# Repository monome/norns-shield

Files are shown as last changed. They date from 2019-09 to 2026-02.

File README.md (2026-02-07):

# norns-shield

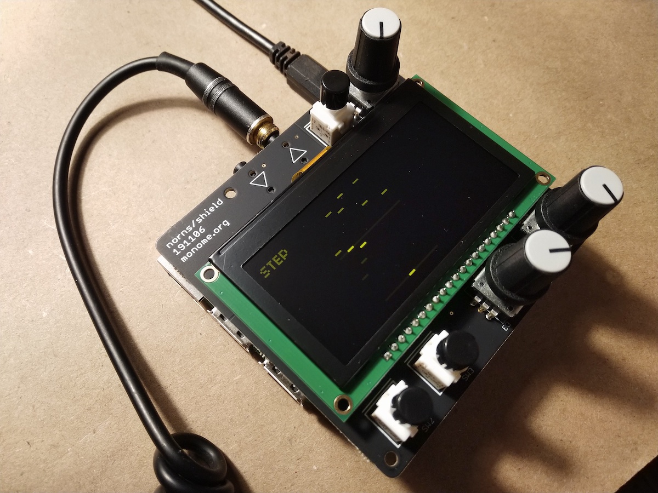
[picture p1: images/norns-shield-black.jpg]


minimal/tiny open-source/DIY shield for Raspberry Pi boards, providing hardware compatibility with the [norns](https://monome.org/docs/norns) ecosystem. designed by monome (brian crabtree, aka @tehn).

all discussion happens at [llllllll.co](https://llllllll.co/t/norns-shield-final/58810).

please be very aware that this project is no longer directly supported by [monome](https://monome.org). do not email us asking for build help or debugging. we also no longer sell boards or kits, we do not have leftovers laying around, and we do not provide repair services.

## donate

we've made these files freely available to further the exploration and design of new musical instruments. the shield relies on years of development, and we continue to maintain and evolve the platform. we hope you'll consider making a donation towards this effort.

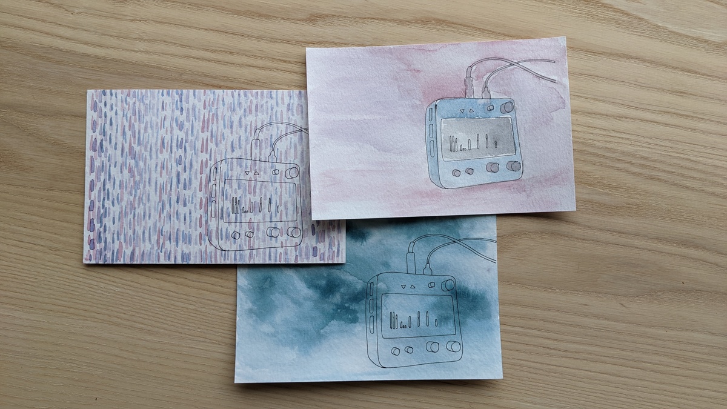
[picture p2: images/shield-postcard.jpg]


direct donations accepted via [paypal](https://paypal.me/tehn/20).

## specifications

- audio codec: CS4270 (or CS4271 on v211028)
- audio jacks: 3.5mm stereo in/out, line level
- OLED: NHD-2.7-12864WDW3
- 3x pushbuttons, 3x rotary encoders

## versions

there are three versions of the circuit:

- 191106: original version
- 210330: updated with more robust (through hole) audio jacks, better noise isolation
- 211028: different codec (due to semiconductor shortages) which requires op amps and many many more passives

we _highly_ recommend 210330 if you're building a new board, and we suggest pairing it with a pi 3B+. the Pi 4 will work with all of the above, but the wifi transciever is noisier and the physical footprint does not fit as well because the ethernet and USB ports were moved around. 

all versions are provided here as reference for repairing existing boards.

## troubleshooting

- if using a Pi 4, you may need to cover the top metal of the USB and ethernet ports on the Pi 4 with electrical tape (something nonconductive) to prevent shorting if the assembly is squeezed tight.
- most soldering problems can be solved simply by reheating solder joints. bad solders can result in various problems: screen doesn't turn on, knobs/keys don't work.
- use a good SD card, not a cheap one. if you're having trouble, try using a different card.
- be sure to use the correct power supply. the pi will not power well from a laptop and you'll get confusing errors. get a dedicated 2A USB supply, or very high output USB battery.

## notes

- the shield does not have a headphone output, but headphones work fine on the main output. the headphone gain level within the norns menu does nothing in this case.
- the battery indication will not function, as there's no battery.

## mechanicals

- 2 Female Threaded Hex Standoff Aluminum, 3/16" Hex, 5/16" Long, 2-56 Thread 91780A104
- 2 Female Threaded Hex Standoff Aluminum, 3/16" Hex, 5/8" Long, 2-56 Thread 91780A111
- 2 Female Threaded Hex Standoff Aluminum, 3/16" Hex, 3/4" Long, 2-56 Thread 91780A113
- 4 Male-Female Threaded Hex Standoff Aluminum, 3/16" Hex Size, 1/2" Long, 2-56 Thread Size 93505A213
- 4 Off-White Nylon Unthreaded Spacer 1/4" OD, 3/32" Long, for Number 6 Screw Size 94639A247
- 8 Black-Oxide 18-8 Stainless Steel Pan Head Phillips Screws 2-56 Thread, 1/4" Long 91249A050
- 2 Black-Oxide 18-8 Stainless Steel Pan Head Phillips Screws 2-56 Thread, 3/8" Long 91249A054

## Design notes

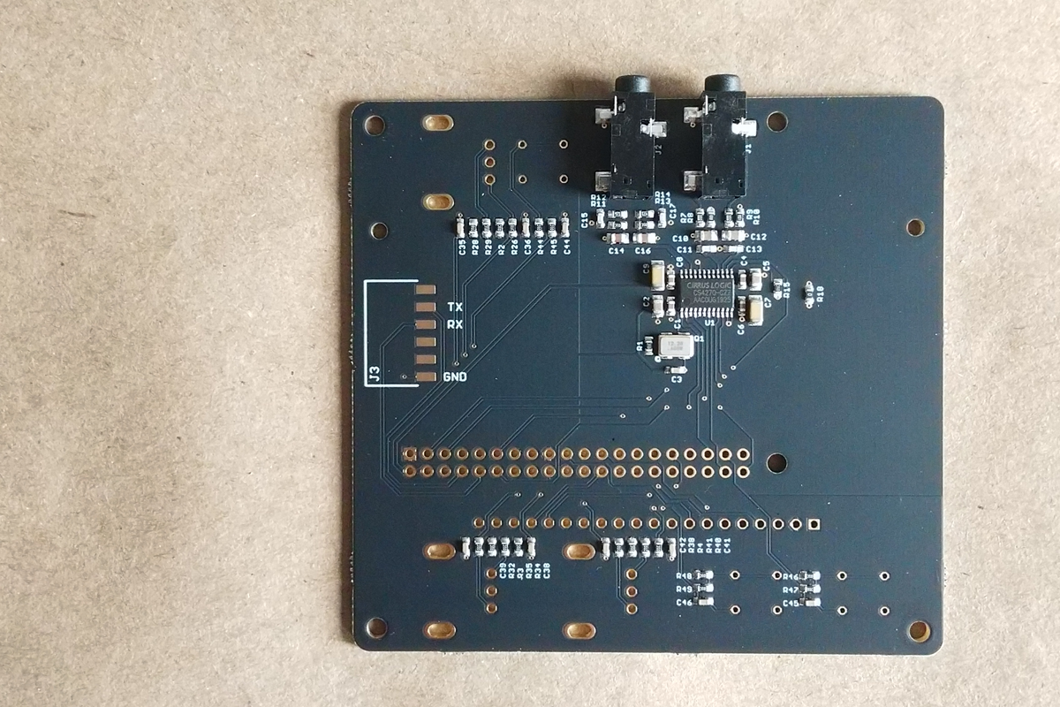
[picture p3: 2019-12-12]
images/norns-shield.png

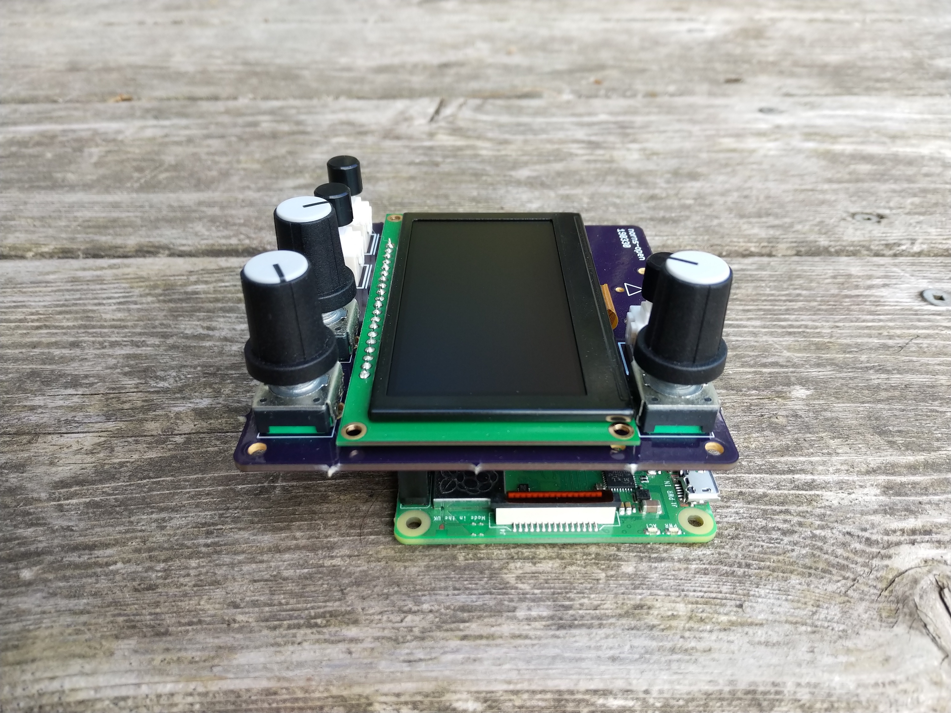
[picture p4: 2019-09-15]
images/norns-shield-side.jpg

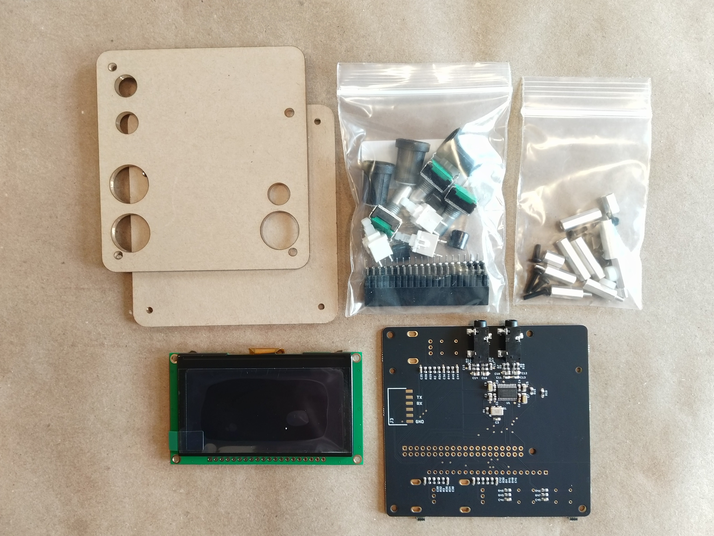
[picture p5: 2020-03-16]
images/ns-kit.jpg

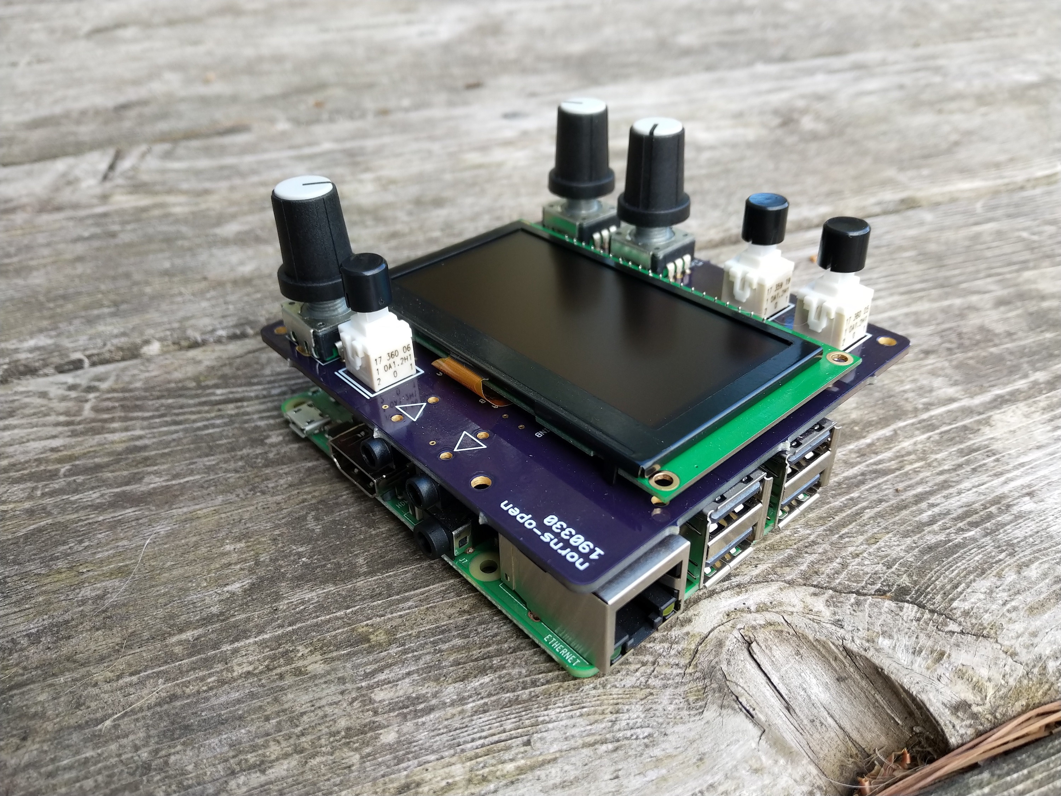
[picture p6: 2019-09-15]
images/norns-shield-angle.jpg

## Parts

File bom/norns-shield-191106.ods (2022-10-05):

Query | Qty | Manufacturer | MPN | Octopart URL | Part Description | Description | Schematic Reference
PEC11R-4015F-N0024 | 3 | Bourns | PEC11R-4015F-N0024 | https://octopart.com/pec11r-4015f-n0024-bourns-26648251 | 24 Pulse Incremental Mechanical Rotary Encoder w/ 6 mm Flat Shaft | Through Hole | ENC
1212-1105-ND | 1 | Preci-Dip | 310-87-120-41-001101 | https://octopart.com/310-87-120-41-001101-preci-dip-21424261 | Conn Socket Strip SKT 20 POS 2.54mm Solder ST Thru-Hole | OLED128X64 | U$1
PVA1 OA H1 1.2N V2 | 3 | C&K Components | PVA1OAH11.2NV2 | https://octopart.com/pva1oah11.2nv2-c%26k+components-47645791 | Switch Push Button DPST Square Button 0.1A 32VDC Momentary Contact PC Pins Thru-Hole | PVA1 | SW1, SW2, SW3
1528-1969-ND | 1 | Adafruit Industries | 1992 | https://octopart.com/1992-adafruit+industries-53880115 | GPIO Header for Raspberry Pi A+/B+ - Tall 2x20 Female Header | RASPI_BOARD_B+#_E3 | X1
1212-1149-ND | 1 | Preci-Dip | 350-80-120-00-001101 | https://octopart.com/350-80-120-00-001101-preci-dip-21642300 | Conn Unshrouded Header HDR 20 POS 2.54mm Solder ST Thru-Hole Box | for OLED
NHD-2.7-12864WDY3 | 1 | Newhaven Display | NHD-2.7-12864WDY3 | https://octopart.com/nhd-2.7-12864wdy3-newhaven+display-84706410 | OLED Displays & Accessories 2.7 in Yellow OLED 128 x 64 | OLED
311-0.0GRTR-ND | 1 | Yageo | RC0603JR-070RL | https://octopart.com/rc0603jr-070rl-yageo-1241539 | RC Series 0603 0.1 W 0 Ohm Jumper Surface Mount Thick Film Chip Resistor | 0 | R18
RC0603FR-071K5L | 2 | Yageo | RC0603FR-071K5L | https://octopart.com/rc0603fr-071k5l-yageo-55458478 | Res General Purpose Thick Film 0603 1.5K Ohm 1% 1/10W ±100ppm/°C Molded SMD Paper T/R | 1.5k | R8, R10
311-1343-2-ND | 4 | Yageo | CC0603ZRY5V9BB104 | https://octopart.com/cc0603zry5v9bb104-yageo-4507169 | Multilayer Ceramic Capacitor, 0.1 uF, 50 V, -20, +80%, Y5V, 0603 [1608 Metric] | 100n | C1, C4, C6, C8
RC0603FR-0710KL | 22 | Yageo | RC0603FR-0710KL | https://octopart.com/rc0603fr-0710kl-yageo-40025538 | Res General Purpose Thick Film 0603 10K Ohm 1% 1/10W ±100ppm/°C Molded SMD Paper T/R | 10k | R1, R2, R3, R4, R11, R13, R15, R26, R28, R29, R32, R34, R35, R38, R40, R41, R44, R45, R46, R47, R48, R49
CC0603KRX7R9BB103 | 10 | Yageo | CC0603KRX7R9BB103 | https://octopart.com/cc0603krx7r9bb103-yageo-192938 | Multilayer Ceramic Capacitor, 0.01 uF, 50 V, ± 10%, X7R, 0603 [1608 Metric] | 10n | C3, C35, C36, C38, C39, C41, C42, C44, C45, C46
GRM21BR61E106KA73L | 4 | Murata | GRM21BR61E106KA73L | https://octopart.com/grm21br61e106ka73l-murata-11231261 | Multilayer Ceramic Capacitor, 10 uF, 25 V, ± 10%, X5R, 0805 [2012 Metric] | 10u | C2, C5, C10, C12
GRM1885C1H221JA01D | 2 | Murata | GRM1885C1H221JA01D | https://octopart.com/grm1885c1h221ja01d-murata-196153 | Multilayer Ceramic Capacitor, 220 pF, 50 V, ± 5%, C0G (NP0), 0603 [1608 Metric] | 220p COG | C11, C13
GRM1885C1H272JA01D | 2 | Murata | GRM1885C1H272JA01D | https://octopart.com/grm1885c1h272ja01d-murata-196902 | Multilayer Ceramic Capacitor, 2700 pF, 50 V, ± 5%, C0G (NP0), 0603 [1608 Metric] | 2700p COG | C15, C17
RC0603FR-073K3L | 2 | Yageo | RC0603FR-073K3L | https://octopart.com/rc0603fr-073k3l-yageo-40011875 | Res General Purpose Thick Film 0603 3.3K Ohm 1% 1/10W ±100ppm/°C Molded SMD Paper T/R | 3.3k | R7, R9
CGA4J3X5R1E335M125AB | 2 | TDK | CGA4J3X5R1E335M125AB | https://octopart.com/cga4j3x5r1e335m125ab-tdk-28170883 | Multilayer Ceramic Capacitor, 3.3 uF, 25 V, ± 20%, X5R, 0805 [2012 Metric] | 3.3u | C14, C16
RC0603FR-07470RL | 2 | Yageo | RC0603FR-07470RL | https://octopart.com/rc0603fr-07470rl-yageo-39823780 | Res General Purpose Thick Film 0603 470 Ohm 1% 1/10W ±100ppm/°C Molded Paper T/R | 470 | R12, R14
C3216X5R1E476M160AC | 2 | TDK | C3216X5R1E476M160AC | https://octopart.com/c3216x5r1e476m160ac-tdk-25947783 | Multilayer Ceramic Capacitor, 47 uF, 25 V, ± 20%, X5R, 1206 [3216 Metric] | 47u | C7, C9
ASFL1-12.288MHZ-EC-T | 1 | Abracon | ASFL1-12.288MHZ-EC-T | https://octopart.com/asfl1-12.288mhz-ec-t-abracon-317620 | Oscillator XO 12.288MHz 50ppm 15pF (Stability) HCMOS/TTL 60% 3.3V 4-Pin SMD T/R | ASFL-12.288mhz | Q1
CS4270-CZZ | 1 | Cirrus Logic | CS4270-CZZ | https://octopart.com/cs4270-czz-cirrus+logic-428038 | Audio Codec 2ADC / 2DAC 24-Bit 24-Pin TSSOP Rail | CS4270 | U1
SJ-3523-SMT-TR | 2 | CUI Devices | SJ-3523-SMT-TR | https://octopart.com/sj-3523-smt-tr-cui+devices-106234235 | 3.5 mm, Stereo, Right Angle, Surface Mount (SMT), Audio Jack Connector | AUDIO-JACK | J1, J2

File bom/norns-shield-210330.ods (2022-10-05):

Query | Qty | Manufacturer | MPN | Octopart URL | Part Description | Description | Schematic Reference
TSW-120-05-T-S | 1 | Samtec | TSW-120-05-T-S | https://octopart.com/tsw-120-05-t-s-samtec-271715 | Headers & Wire Housings Classic PCB Header Strips, 0.100 pitch | OLED HEADER | U$1
TPS793475DBVR | 1 | Texas Instruments | TPS793475DBVR | https://octopart.com/tps793475dbvr-texas+instruments-525242 | Ldo Voltage Regulator, 4.75V, 0.2A, 5-SOT-23, Full Reel | TPS793 | U11
RC0603FR-07590RL | 2 | Yageo | RC0603FR-07590RL | https://octopart.com/rc0603fr-07590rl-yageo-1229374 | Res Thick Film 0603 590 Ohm 1% 0.1W(1/10W) ±100ppm/C Pad SMD T/R | 590 | R12, R14
RC0603FR-074K99L | 2 | Yageo | RC0603FR-074K99L | https://octopart.com/rc0603fr-074k99l-yageo-55458490 | Res General Purpose Thick Film 0603 4.99k Ohm 1% 1/10W ±100ppm/°C Molded Paper T/R | 4.99k | R7, R9
RC0603FR-0710KL | 24 | Yageo | RC0603FR-0710KL | https://octopart.com/rc0603fr-0710kl-yageo-40025538 | Res General Purpose Thick Film 0603 10K Ohm 1% 1/10W ±100ppm/°C Molded SMD Paper T/R | 10k | R1, R2, R3, R4, R8, R10, R11, R13, R15, R26, R28, R29, R32, R34, R35, R38, R40, R41, R44, R45, R46, R47, R48, R49
PVA1 OA H1 1.2N V2 | 3 | C&K Components | PVA1OAH11.2NV2 | https://octopart.com/pva1oah11.2nv2-c%26k+components-47645791 | Switch Push Button DPST Square Button 0.1A 32VDC Momentary Contact PC Pins Thru-Hole | PVA1 | SW1, SW2, SW3
PEC11R-4015F-N0024 | 3 | Bourns | PEC11R-4015F-N0024 | https://octopart.com/pec11r-4015f-n0024-bourns-26648251 | 24 Pulse Incremental Mechanical Rotary Encoder w/ 6 mm Flat Shaft | Through Hole | ENC
NHD-2.7-12864WDY3 | 1 | Newhaven Display | NHD-2.7-12864WDY3 | https://octopart.com/nhd-2.7-12864wdy3-newhaven+display-84706410 | OLED Displays & Accessories 2.7 in Yellow OLED 128 x 64
GRM1885C1H272JA01D | 2 | Murata | GRM1885C1H272JA01D | https://octopart.com/grm1885c1h272ja01d-murata-196902 | Multilayer Ceramic Capacitor, 2700 pF, 50 V, ± 5%, C0G (NP0), 0603 [1608 Metric] | 2700p COG | C15, C17
GRM1885C1H221JA01D | 2 | Murata | GRM1885C1H221JA01D | https://octopart.com/grm1885c1h221ja01d-murata-196153 | Multilayer Ceramic Capacitor, 220 pF, 50 V, ± 5%, C0G (NP0), 0603 [1608 Metric] | 220p COG | C11, C13
GRM21BR61E106KA73L | 5 | Murata | GRM21BR61E106KA73L | https://octopart.com/grm21br61e106ka73l-murata-11231261 | Multilayer Ceramic Capacitor, 10 uF, 25 V, ± 10%, X5R, 0805 [2012 Metric] | 10u | C2, C5, C10, C12, C43
CS4270-CZZ | 1 | Cirrus Logic | CS4270-CZZ | https://octopart.com/cs4270-czz-cirrus+logic-428038 | Audio Codec 2ADC / 2DAC 24-Bit 24-Pin TSSOP Rail | CS4270 | U1
CGA4J3X5R1E335M125AB | 2 | TDK | CGA4J3X5R1E335M125AB | https://octopart.com/cga4j3x5r1e335m125ab-tdk-28170883 | Multilayer Ceramic Capacitor, 3.3 uF, 25 V, ± 20%, X5R, 0805 [2012 Metric] | 3.3u | C14, C16
CC0603KRX7R9BB103 | 11 | Yageo | CC0603KRX7R9BB103 | https://octopart.com/cc0603krx7r9bb103-yageo-192938 | Multilayer Ceramic Capacitor, 0.01 uF, 50 V, ± 10%, X7R, 0603 [1608 Metric] | 10n | C3, C35, C36, C38, C39, C41, C42, C44, C45, C46, C88
C3216X5R1E476M160AC | 2 | TDK | C3216X5R1E476M160AC | https://octopart.com/c3216x5r1e476m160ac-tdk-25947783 | Multilayer Ceramic Capacitor, 47 uF, 25 V, ± 20%, X5R, 1206 [3216 Metric] | 47u | C7, C9
BLM21PG331SN1D | 1 | Murata | BLM21PG331SN1D | https://octopart.com/blm21pg331sn1d-murata-755248 | Ferrite Beads Multi-Layer 330Ohm 25% 100MHz 1.5A 70mOhm DCR 0805 Automotive Paper T/R | FERRITE | L3
ASFL1-12.288MHZ-EC-T | 1 | Abracon | ASFL1-12.288MHZ-EC-T | https://octopart.com/asfl1-12.288mhz-ec-t-abracon-317620 | Oscillator XO 12.288MHz 50ppm 15pF (Stability) HCMOS/TTL 60% 3.3V 4-Pin SMD T/R | ASFL-12.288mhz | Q1
4832.233 | 2 | Schurter | 4832.233 | https://octopart.com/4832.2330-schurter-6626217 | Conn 3.5MM Audio Jack SKT 4 POS Solder RA Thru-Hole 4 Terminal 1 Port | JACK-TRS-SW | J-IN, J-OUT
1528-1969-ND | 1 | Adafruit Industries | 1992 | https://octopart.com/1992-adafruit+industries-53880115 | GPIO Header for Raspberry Pi A+/B+ - Tall 2x20 Female Header | RASPI_BOARD_B+#_E3 | X1
311-1343-2-ND | 6 | Yageo | CC0603ZRY5V9BB104 | https://octopart.com/cc0603zry5v9bb104-yageo-4507169 | Multilayer Ceramic Capacitor, 0.1 uF, 50 V, -20, +80%, Y5V, 0603 [1608 Metric] | 100n | C1, C4, C6, C8, C47, C63

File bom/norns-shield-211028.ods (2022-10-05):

Query | Qty | Manufacturer | MPN | Octopart URL | Part Description | Description | Schematic Reference
311-1343-2-ND | 6 | Yageo | CC0603ZRY5V9BB104 | https://octopart.com/cc0603zry5v9bb104-yageo-4507169 | 0603 0.1 uF 50 V -20 / +80 % Tolerance Y5V SMT Multilayer Ceramic Capacitor | 100n | C1, C6, C8, C18, C47, C63
RC0603FR-0710KL | 22 | Yageo | RC0603FR-0710KL | https://octopart.com/rc0603fr-0710kl-yageo-40025538 | Res General Purpose Thick Film 0603 10K Ohm 1% 1/10W ±100ppm/°C Molded SMD Paper T/R | 10k | R1, R2, R3, R4, R8, R9, R15, R26, R28, R29, R32, R34, R35, R38, R40, R41, R44, R45, R46, R47, R48, R49
CC0603KRX7R9BB103 | 14 | Yageo | CC0603KRX7R9BB103 | https://octopart.com/cc0603krx7r9bb103-yageo-192938 | SMD Multilayer Ceramic Capacitor, 10000 pF, 50 V, 0603 [1608 Metric], ± 10%, X7R, CC Series | 10n | C3, C14, C16, C20, C35, C36, C38, C39, C41, C42, C44, C45, C46, C88
GRM21BR61E106KA73L | 5 | Murata | GRM21BR61E106KA73L | https://octopart.com/grm21br61e106ka73l-murata-11231261 | 0805 10 uF 25 V ±10% Tolerance X5R SMT Multilayer Ceramic Capacitor | 10u | C2, C5, C10, C19, C43
RC0603FR-071K33L | 2 | Yageo | RC0603FR-071K33L | https://octopart.com/rc0603fr-071k33l-yageo-1209398 | Res Thick Film 0603 1.33K Ohm 1% 0.1W(1/10W) ±100ppm/C Pad SMD T/R | 1k33 | R11, R19
RC0603FR-071K5L | 2 | Yageo | RC0603FR-071K5L | https://octopart.com/rc0603fr-071k5l-yageo-55458478 | Res General Purpose Thick Film 0603 1.5K Ohm 1% 1/10W ±100ppm/°C Molded SMD Paper T/R | 1k5 | R13, R21
C0603C152F1GAC7867 | 2 | KEMET | C0603C152F1GAC7867 | https://octopart.com/c0603c152f1gac7867-kemet-51214920 | Cap Ceramic 0.0015uF 100V C0G 1% SMD 0603 125°C Punched Paper T/R | 1n5 | C22, C28
GRM1885C1H222JA01J | 2 | Murata | GRM1885C1H222JA01J | https://octopart.com/grm1885c1h222ja01j-murata-16412836 | 0603 50 V 2200 pF ±5% Tolerance C0G Multilayer Ceramic Capacitor | 2200p COG | C15, C25
CL31A226MOCLNNC | 4 | Samsung | CL31A226MOCLNNC | https://octopart.com/cl31a226moclnnc-samsung-19832800 | Cap Ceramic 22uF 16V X5R 20% SMD 1206 85°C Cardboard T/R | 22u | C21, C24, C27, C30
GRM1885C1H272JA01D | 2 | Murata | GRM1885C1H272JA01D | https://octopart.com/grm1885c1h272ja01d-murata-196902 | 0603 2.7 nF 50 V ±5 % Tolerance C0G SMT Multilayer Ceramic Capacitor | 2700p COG | C4, C13
RC0603FR-072K32L | 2 | Yageo | RC0603FR-072K32L | https://octopart.com/rc0603fr-072k32l-yageo-1384316 | Res Thick Film 0603 2.32K Ohm 1% 0.1W(1/10W) ±100ppm/C Pad SMD T/R | 2k32 | R16, R23
CL10C471JB8NFNC | 2 | Samsung | CL10C471JB8NFNC | https://octopart.com/cl10c471jb8nfnc-samsung-19832014 | Cap Ceramic 470pF 50V C0G 5% SMD 0603 125°C Paper T/R | 470p | C23, C29
GMC10CG471J50NTD | 2 | Cal-Chip Electronics | GMC10CG471J50NTD | https://octopart.com/gmc10cg471j50ntd-cal-chip+electronics-4681919 | Cap Cer 470PF 50V C0G/NP0 0603 | 470p COG | C11, C12
RC0603FR-0747KL | 2 | Yageo | RC0603FR-0747KL | https://octopart.com/rc0603fr-0747kl-yageo-1369017 | Res Thick Film 0603 47K Ohm 1% 1/10W ±100ppm/°C Molded SMD Paper T/R | 47k | R18, R25
C3216X5R1E476M160AC | 2 | TDK | C3216X5R1E476M160AC | https://octopart.com/c3216x5r1e476m160ac-tdk-25947783 | C Series 1206 47 uF 25 V ±20 % Tolerance X5R SMT Multilayer Ceramic Capacitor | 47u | C7, C9
RC0603FR-074K42L | 2 | Yageo | RC0603FR-074K42L | https://octopart.com/rc0603fr-074k42l-yageo-39829078 | Res Thick Film 1.6 x 0.8 mm 4.42K Ohm 1% 0.1W(1/10W) 100ppm/ C Molded SMD Paper T/R | 4k42 | R12, R20
RC0603FR-074K99L | 2 | Yageo | RC0603FR-074K99L | https://octopart.com/rc0603fr-074k99l-yageo-55458490 | Res General Purpose Thick Film 0603 4.99k Ohm 1% 1/10W ±100ppm/°C Molded Paper T/R | 4k99 | R17, R24
RC0603FR-07560RL | 2 | Yageo | RC0603FR-07560RL | https://octopart.com/rc0603fr-07560rl-yageo-1265587 | Res Thick Film 0603 560 Ohm 1% 0.1W(1/10W) ±100ppm/C Pad SMD T/R | 560 | R27, R30
RC0603FR-07634RL | 2 | Yageo | RC0603FR-07634RL | https://octopart.com/rc0603fr-07634rl-yageo-1213507 | Res Thick Film 0603 634 Ohm 1% 0.1W(1/10W) ±100ppm/C Pad SMD T/R | 634 | R5, R10
C0603C682J5GAC7867 | 2 | KEMET | C0603C682J5GACTU | https://octopart.com/c0603c682j5gactu-kemet-12793182 | 0603 C 6.8nF Ceramic Multilayer Capacitor; 50 V; +125degC; C0G Dielectric; +/-5% | 6n8 | C17, C26
RC0603FR-07715RL | 2 | Yageo | RC0603FR-07715RL | https://octopart.com/rc0603fr-07715rl-yageo-1167489 | Res Thick Film 0603 715 Ohm 1% 0.1W(1/10W) ±100ppm/°C Pad SMD T/R | 715 | R14, R22
RC0603FR-0791RL | 2 | Yageo | RC0603FR-0791RL | https://octopart.com/rc0603fr-0791rl-yageo-1235547 | Res Thick Film 0603 91 Ohm 1% 0.1W(1/10W) ±100ppm/°C Pad SMD T/R | 91 | R6, R7
ASFL1-12.288MHZ-EC-T | 1 | Abracon | ASFL1-12.288MHZ-EC-T | https://octopart.com/asfl1-12.288mhz-ec-t-abracon-317620 | Oscillator XO 12.288MHz 50ppm 15pF (Stability) HCMOS/TTL 60% 3.3V 4-Pin SMD T/R | ASFL-12.288mhz | Q1
CS4271-CZZ | 1 | Cirrus Logic | CS4271-CZZ | https://octopart.com/cs4271-czz-cirrus+logic-428039 | Audio Codec 2ADC / 2DAC 24-Bit 28-Pin TSSOP Tube | CS4271 | U1
PEC11R-4015F-N0024 | 3 | Bourns | PEC11R-4015F-N0024 | https://octopart.com/pec11r-4015f-n0024-bourns-26648251 | 24 Pulse Incremental Mechanical Rotary Encoder w/ 6 mm Flat Shaft; Through Hole | ENC | E1, E2, E3
BLM21PG331SN1D | 1 | Murata | BLM21PG331SN1D | https://octopart.com/blm21pg331sn1d-murata-755248 | Ferrite Beads Multi-Layer 330Ohm 25% 100MHz 1.5A 70mOhm DCR 0805 Automotive Paper T/R | FERRITE | L3
4832.233 | 2 | Schurter | 4832.233 | https://octopart.com/4832.2330-schurter-6626217 | Conn 3.5MM Audio Jack SKT 4 POS Solder RA Thru-Hole 4 Terminal 1 Port | JACK-TRS-SW | J-IN, J-OUT
TSW-120-05-T-S | 1 | Samtec | TSW-120-05-T-S | https://octopart.com/tsw-120-05-t-s-samtec-271715 | Headers & Wire Housings Classic PCB Header Strips, 0.100 pitch | OLED128X64 | U$1
PVA1 OA H1 1.2N V2 | 3 | C&K Components | PVA1 OA H1 1.2N V2 | https://octopart.com/pva1+oa+h1+1.2n+v2-c%26k+components-31930236 | Switch Push Button DPST Square Button 0.1A 32VDC Momentary Contact PC Pins Thru-Hole | PVA1 | SW1, SW2, SW3
1528-1969-ND | 1 | Adafruit Industries | 1992 | https://octopart.com/1992-adafruit+industries-53880115 | GPIO Header for Raspberry Pi A+/B+ - Tall 2x20 Female Header | RASPI_BOARD_B+#_E3 | X1
TSV358AIDT | 3 | STMicroelectronics | TSV358AIDT | https://octopart.com/tsv358aidt-stmicroelectronics-1245014 | General purpose low voltage rail to rail input/output op-amp, -40 to 125°C, SO-8, Tape and Reel | TL072D | IC1, IC2, IC4
TPS793475DBVR | 1 | Texas Instruments | TPS793475DBVR | https://octopart.com/tps793475dbvr-texas+instruments-525242 | Ldo Voltage Regulator, 4.75V, 0.2A, 5-SOT-23, Full Reel | TPS793 | U11
NHD-2.7-12864WDY3 | 1 | Newhaven Display | NHD-2.7-12864WDY3 | https://octopart.com/nhd-2.7-12864wdy3-newhaven+display-84706410 | OLED Displays & Accessories 2.7 in Yellow OLED 128 x 64

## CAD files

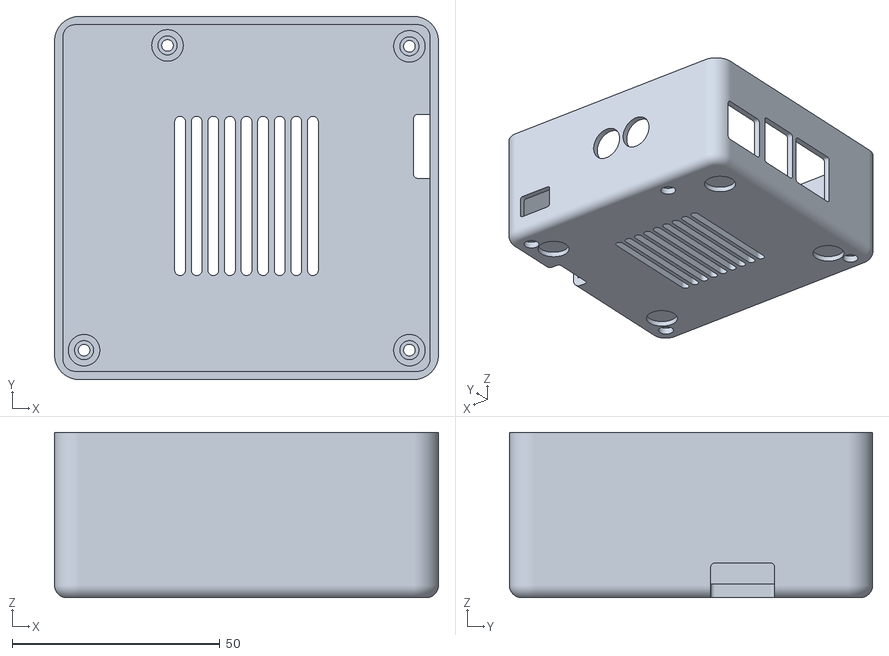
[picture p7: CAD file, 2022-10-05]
cad/norns-shield.stl
92.5 x 87.5 x 39.8

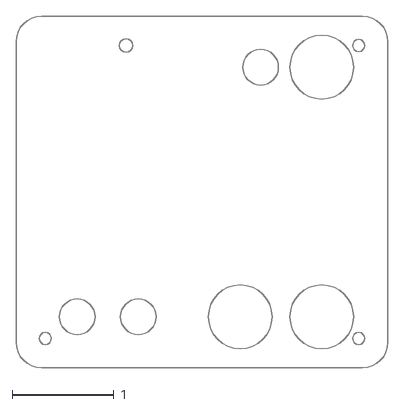
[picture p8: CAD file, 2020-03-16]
cad/norns-shield-plate.dxf
3.65 x 3.45

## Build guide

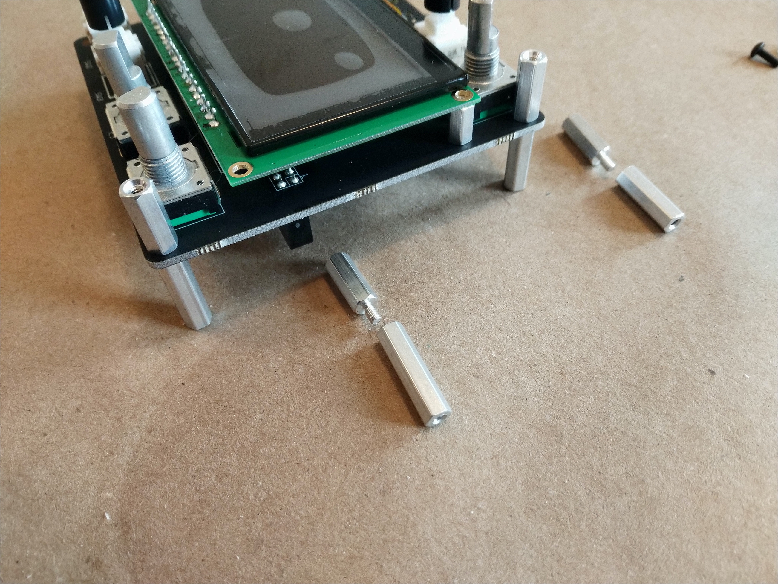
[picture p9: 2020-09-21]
images/assembly/ns-5.jpg

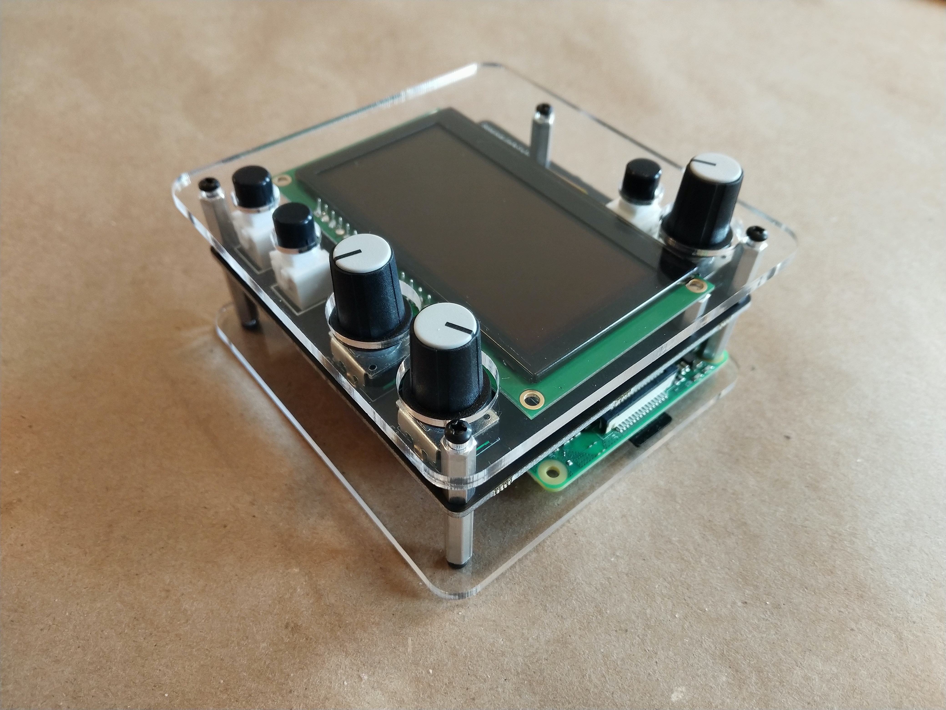
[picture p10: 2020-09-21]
images/assembly/ns-8.jpg

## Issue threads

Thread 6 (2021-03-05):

Cannot connect via SSH

andneuma, 2021-03-05:
Hey everyone,

I got an assembled shield which I'm not able to connect to via SSH. I always end up receiving

`Received disconnect from <IP> port 22:2: Too many authentication failures`

Not working via Wifi nor Ethnernet. I already tried with the current image liested in the Readme over here but the problem remains. Since HDMI out is disabled per default I'm clueless on how to access the device's OS. Do you have any ideas?

Portscanning the device revealed the port is open.

The maiden webservice is working fine.

Thanks a lot in advance!

andneuma, 2021-03-05:
Allright, seems to be an issue with my SSH configuration, works from another computer. Gonna close

Closed 2021-03-05.

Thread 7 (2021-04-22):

BOM not available

tapecanvas, 2021-04-22:
The link to the Octopart BOM does not populate with components. I am trying to find the SMD parts required for the build.
FOUND WORK AROUND: exporting the BOM to CSV gets me what I need.

tehn, 2021-04-23:
this is an octopart issue. they should resolve it soon.

Closed 2021-04-23.

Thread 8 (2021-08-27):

Are the eagle files for the 210330 PCB version which is reducing noise available?

iUltimateLP, 2021-08-27:
Title says it all :) Will the files be uploaded here at some point?

Thanks so much!

Atarity, 2021-09-04:
As far as I know it is not yet. Pretty sure the reason is: it is not about layout publishing. They need to make complete release. That means:
- updating .brd and .sch
- updating BOM on Octopart
- updating assembling tutorial
- updating pictures
- triple check everything and make a tag or release
- write update topic to the Lines
- Collect endless likes. 🔥

Sounds like lots of work needs to be done in a row.

By the way: I'm not a maintainer, so above is my only assumption. I'm waiting updated layout and BOM too.

Mynasru, 2021-09-30:
Is it known what exactly changed with the new revision?

iUltimateLP, 2021-09-30:
> Is it known what exactly changed with the new revision?

Well I'm not skilled enough to replace parts myself unfortunately

tehn, 2021-09-30:
audio supply cleaned up by separating with a LDO and conditioning. TH audio jacks. tuned gain stages.

this is all a bit moot given the unavailability of the codec. it's possible to do a version with a different codec but it'd take a lot of engineering and software. i'm working on such a rev (no timeline) so i'd suggest waiting for that.

jpnielsen, 2022-06-02:
211028 revision shield schematic please.

Digikey has 0 cs4270 available (unless I buy 4000 on a reel)

iUltimateLP, 2022-08-11:
Any updates on this?

Closed 2021-09-30.

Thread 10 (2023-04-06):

readme troubleshooting clarification

jaseknighter, 2023-04-06:
in the troubleshooting section of the readme, it states: "if using a pi 4, you may need to cover these ports on the Pi 4 with electrical tape (something nonconductive) to prevent shorting if the assembly is squeezed tight."

however, it isn't clear which ports are being referenced, so i think it would help to clarify this.

dndrks, 2023-04-23:
thank you @jaseknighter !

Closed 2023-04-23.

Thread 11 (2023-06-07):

norns-shield-210330.ods BOM lacks the female header for the OLED

x37v, 2023-06-07:
The BOM includes the male pin header but not the female side

FishPhd, 2023-09-28:
Do you have a link to the part? Building mine and don't know what size the header should be

x37v, 2023-10-02:
@FishPhd a friend bought the part but I've asked him to give me the info if he can

tehn, 2023-10-08:
you can direct solder it to the board, though the screen won't be removable.

Closed 2023-10-08.

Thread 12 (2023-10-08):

norns-shield-210330.brd - error loading

jonpb, 2023-10-08:
Hi,
both Eagle and Fusion 360 give the same error with
norns-shield-210330.brd
line 8, column 157: This is not an EAGLE file.

I would like to confirm possible anonolies and details with the pcb inscriptions on the board I received before committing to the soldering.
Thanks

tehn, 2023-10-08:
regretfully, Autocad discontinued eagle, after purchasing it from cadsoft. these files were saved with eagle version 7, which was the last version i paid for (when it was owned by cadsoft.)

if autocad abandoned backwards compatibility that's a shame. if someone wants to upload newer versions of these files feel free to PR.

also if someone wants to convert these to kicad, please do.

jonpb, 2023-10-08:
So sorry, I don't know how it happened but the file on my hard drive was wrong. I downloaded the brd file again and it opens fine, even in Fusion 360.

Closed 2023-10-08.

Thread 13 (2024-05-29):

Missing schematic page

Kobreizhyashi, 2024-05-29:
Hi,

I think there's a missing page on the schematic page for the 210330 version.

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

(Looks like The red part is missing, the white part is here)

And I can see on the schema that this is the 1/2 page.

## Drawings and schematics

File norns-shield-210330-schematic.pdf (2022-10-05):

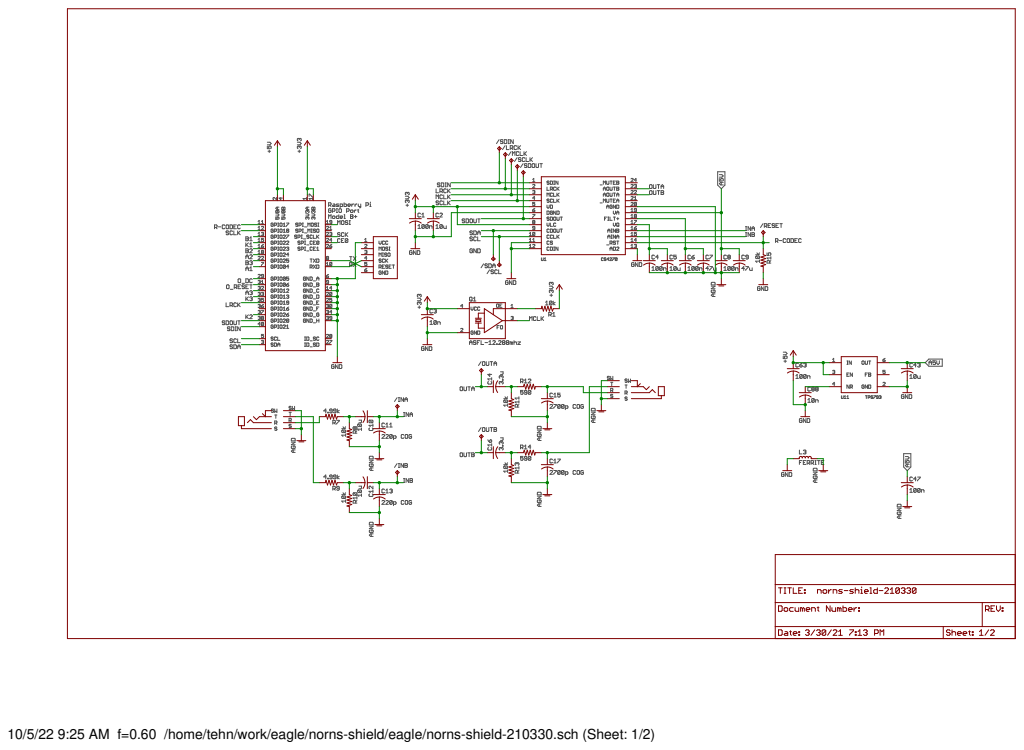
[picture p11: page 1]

10/5/22 9:25 AM f=0.60 /home/tehn/work/eagle/norns-shield/eagle/norns-shield-210330.sch (Sheet: 1/2)

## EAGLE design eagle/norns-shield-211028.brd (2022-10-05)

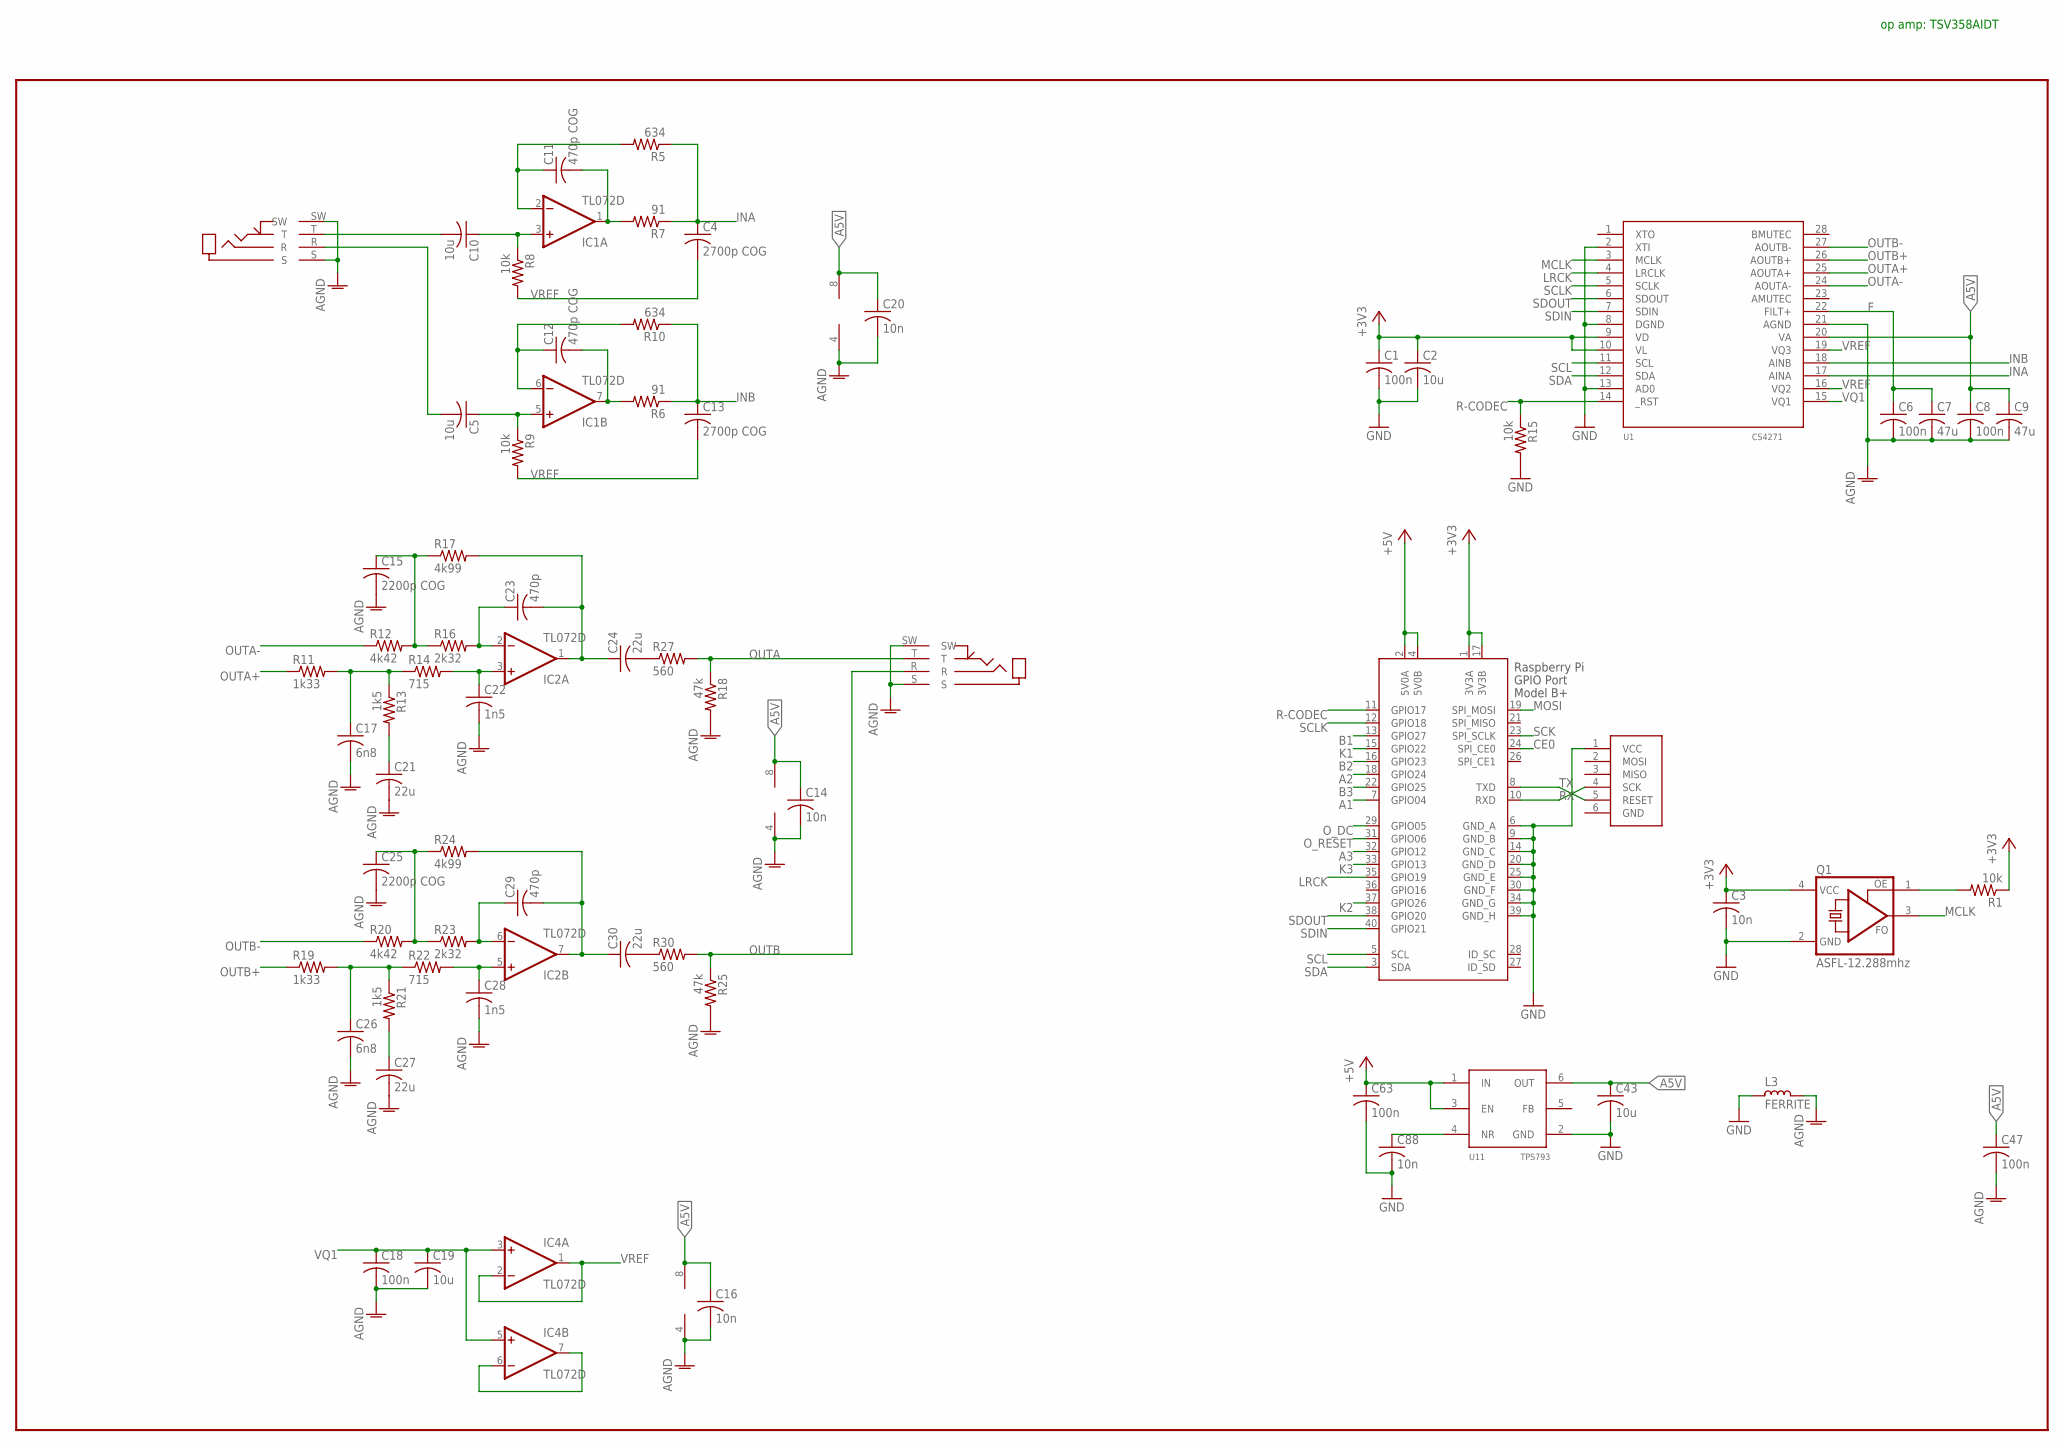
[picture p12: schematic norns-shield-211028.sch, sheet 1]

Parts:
C1, C6, C8, C18, C47, C63: 100n; C0603
C2, C5, C10, C19, C43: 10u; C0805
C3, C14, C16, C20, C88: 10n; C0603
C4, C13: 2700p COG; C0603
C7, C9: 47u; C1206
C11, C12: 470p COG; C0603
C15, C25: 2200p COG; C0603
C17, C26: 6n8; C0603
C21, C24, C27, C30: 22u; C1206
C22, C28: 1n5; C0603
C23, C29: 470p; C0603
IC1, IC2, IC4: TL072D; SO08
J3: ISP-ROW
J-IN: JACK-TRS-SW; JACK4832.2330
J-OUT: JACK-TRS-SW; JACK4832.2330
L3: FERRITE; L0805
Q1: ASFL-12.288mhz; ASF
R1, R8, R9, R15: 10k; R0603
R5, R10: 634; R0603
R6, R7: 91; R0603
R11, R19: 1k33; R0603
R12, R20: 4k42; R0603
R13, R21: 1k5; R0603
R14, R22: 715; R0603
R16, R23: 2k32; R0603
R17, R24: 4k99; R0603
R18, R25: 47k; R0603
R27, R30: 560; R0603
U1: CS4271; SOP28
U11: TPS793; SSOP6
X1: RASPI_BOARD_B+#_E3; RASPI_BOARD_B+_EDGES_3DRILL

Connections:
+3V3: C1.1, C2.1, C3.1, Q1.4 (VCC), R1.1, U1.9 (VD), U1.10 (VL), X1.1 (3V3A), X1.17 (3V3B); also elsewhere on the board
+5V: C63.1, U11.1 (IN), U11.3 (EN), X1.2 (5V0A), X1.4 (5V0B)
A1: X1.7 (GPIO04); also elsewhere on the board
A2: X1.18 (GPIO24); also elsewhere on the board
A3: X1.32 (GPIO12); also elsewhere on the board
A5V: C8.1, C9.1, C14.1, C16.1, C20.1, C43.1, C47.1, IC1.8 (V+), IC2.8 (V+), IC4.8 (V+), U1.20 (VA), U11.6 (OUT)
AGND: C6.2, C7.2, C8.2, C9.2, C14.2, C15.2, C16.2, C17.2, C18.2, C19.2, C20.2, C21.2, C22.2, C25.2, C26.2, C27.2, C28.2, C47.2, IC1.4 (V-), IC2.4 (V-), IC4.4 (V-), J-IN.S, J-IN.SW, J-OUT.S, J-OUT.SW, L3.1, R18.2, R25.2, U1.21 (AGND)
B1: X1.13 (GPIO27); also elsewhere on the board
B2: X1.16 (GPIO23); also elsewhere on the board
B3: X1.22 (GPIO25); also elsewhere on the board
CE0: X1.24 (SPI_CE0); also elsewhere on the board
F: C6.1, C7.1, U1.22 (FILT+)
GND: C1.2, C2.2, C3.2, C43.2, C63.2, C88.2, J3.1 (VCC), L3.2, Q1.2 (GND), R15.2, U1.2 (XTI), U1.8 (DGND), U1.13 (AD0), U11.2 (GND), X1.6 (GND_A), X1.9 (GND_B), X1.14 (GND_C), X1.20 (GND_D), X1.25 (GND_E), X1.30 (GND_F), X1.34 (GND_G), X1.39 (GND_H); also elsewhere on the board
INA: C4.1, R5.1, R7.1, U1.17 (AINA)
INB: C13.1, R6.1, R10.1, U1.18 (AINB)
K1: X1.15 (GPIO22); also elsewhere on the board
K2: X1.37 (GPIO26); also elsewhere on the board
K3: X1.33 (GPIO13); also elsewhere on the board
LRCK: U1.4 (LRCLK), X1.35 (GPIO19)
MCLK: Q1.3 (FO), U1.3 (MCLK)
MOSI: X1.19 (SPI_MOSI); also elsewhere on the board
unnamed: Q1.1 (OE), R1.2
unnamed: C11.1, IC1.2 (-IN), R5.2
unnamed: C11.2, IC1.1 (OUT), R7.2
unnamed: C12.1, IC1.6 (-IN), R10.2
unnamed: C10.2, J-IN.T
unnamed: C10.1, IC1.3 (+IN), R8.1
unnamed: C12.2, IC1.7 (OUT), R6.2
unnamed: C5.2, J-IN.R
unnamed: C5.1, IC1.5 (+IN), R9.1
unnamed: C24.2, R27.1
unnamed: C30.2, R30.1
unnamed: C26.1, R19.2, R21.1, R22.1
unnamed: C17.1, R11.2, R13.1, R14.1
unnamed: C21.1, R13.2
unnamed: C15.1, R12.2, R16.1, R17.1
unnamed: C23.1, IC2.2 (-IN), R16.2
unnamed: C23.2, C24.1, IC2.1 (OUT), R17.2
unnamed: C22.1, IC2.3 (+IN), R14.2
unnamed: IC4.6 (-IN), IC4.7 (OUT)
unnamed: C27.1, R21.2
unnamed: C25.1, R20.2, R23.1, R24.1
unnamed: C29.1, IC2.6 (-IN), R23.2
unnamed: C29.2, C30.1, IC2.7 (OUT), R24.2
unnamed: C28.1, IC2.5 (+IN), R22.2
unnamed: C88.1, U11.4 (NR)
OUTA: J-OUT.T, R18.1, R27.2
OUTA+: R11.1, U1.25 (AOUTA+)
OUTA-: R12.1, U1.24 (AOUTA-)
OUTB: J-OUT.R, R25.1, R30.2
OUTB+: R19.1, U1.26 (AOUTB+)
OUTB-: R20.1, U1.27 (AOUTB-)
O_DC: X1.29 (GPIO05); also elsewhere on the board
O_RESET: X1.31 (GPIO06); also elsewhere on the board
R-CODEC: R15.1, U1.14 (_RST), X1.11 (GPIO17)
RX: J3.4 (SCK), X1.10 (RXD)
SCK: X1.23 (SPI_SCLK); also elsewhere on the board
SCL: U1.11 (SCL), X1.5 (SCL)
SCLK: U1.5 (SCLK), X1.12 (GPIO18)
SDA: U1.12 (SDA), X1.3 (SDA)
SDIN: U1.7 (SDIN), X1.40 (GPIO21)
SDOUT: U1.6 (SDOUT), X1.38 (GPIO20)
TX: J3.5 (RESET), X1.8 (TXD)
VQ1: C18.1, C19.1, IC4.3 (+IN), IC4.5 (+IN), U1.15 (VQ1)
VREF: C4.2, C13.2, IC4.1 (OUT), IC4.2 (-IN), R8.2, R9.2, U1.16 (VQ2), U1.19 (VQ3)

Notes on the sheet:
op amp: TSV358AIDT

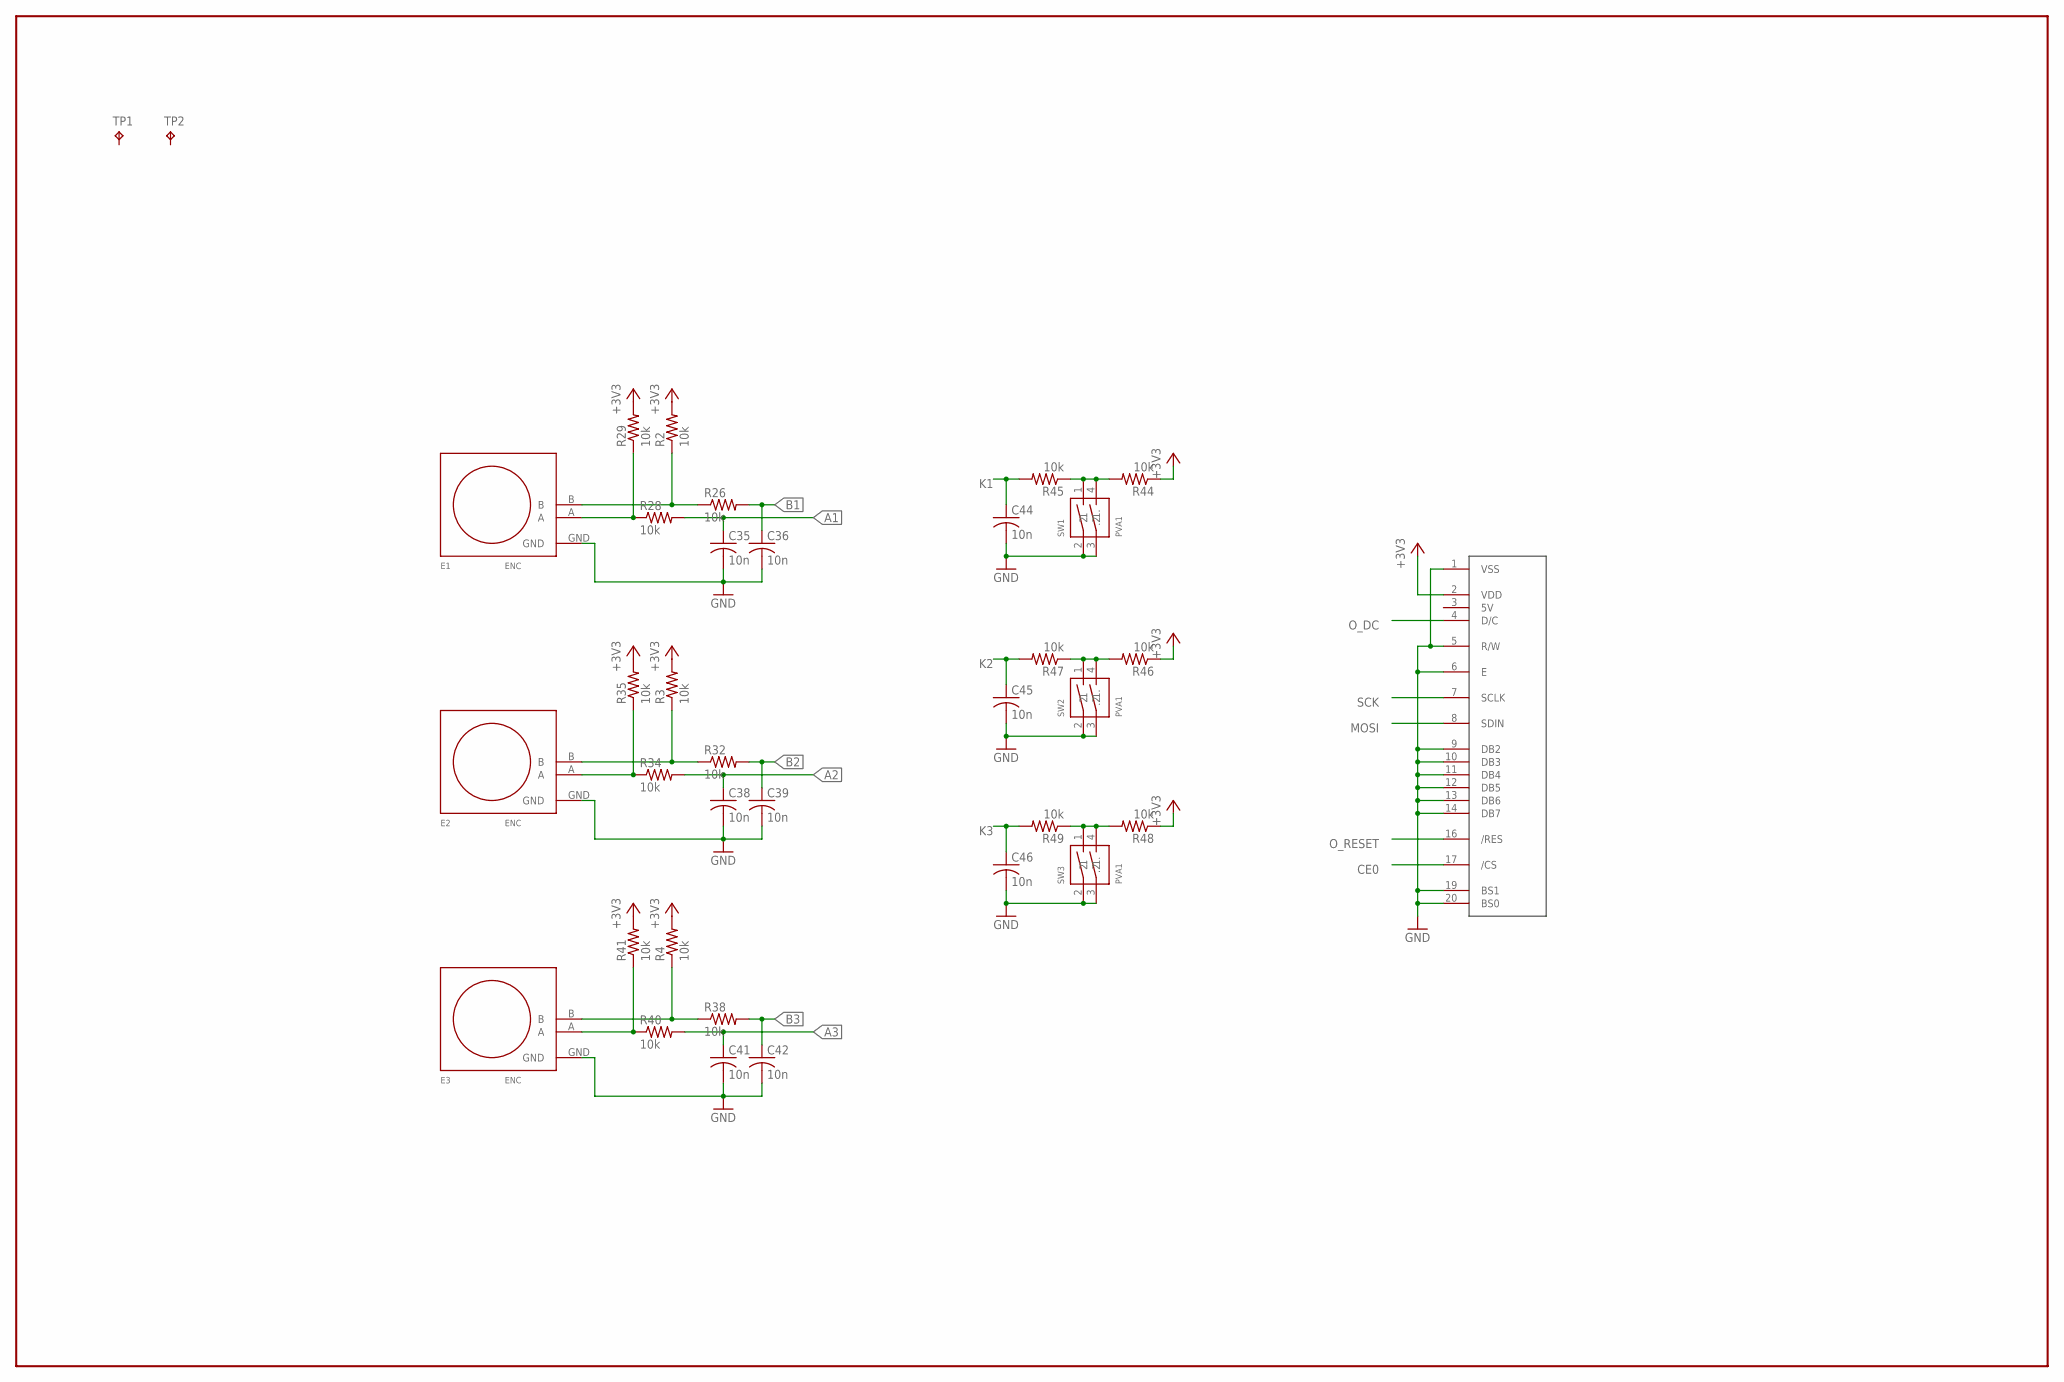
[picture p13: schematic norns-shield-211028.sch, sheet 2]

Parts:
C35, C36, C38, C39, C41, C42, C44, C45, C46: 10n; C0603
E1, E2, E3: ENC; PEC11RN
R2, R3, R4, R26, R28, R29, R32, R34, R35, R38, R40, R41, R44, R45, R46, R47, R48, R49: 10k; R0603
SW1, SW2, SW3: PVA1
TP1, TP2: TPB1,27; B1,27
U$1: OLED128X64; OLED-ALEPH

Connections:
+3V3: R2.2, R3.2, R4.2, R29.2, R35.2, R41.2, R44.1, R46.1, R48.1, U$1.2 (VDD); also elsewhere on the board
A1: C35.1, R28.2; also elsewhere on the board
A2: C38.1, R34.2; also elsewhere on the board
A3: C41.1, R40.2; also elsewhere on the board
B1: C36.1, R26.2; also elsewhere on the board
B2: C39.1, R32.2; also elsewhere on the board
B3: C42.1, R38.2; also elsewhere on the board
CE0: U$1.17 (/CS); also elsewhere on the board
GND: C35.2, C36.2, C38.2, C39.2, C41.2, C42.2, C44.2, C45.2, C46.2, E1.GND, E2.GND, E3.GND, SW1.2 (1), SW1.3 (1.), SW2.2 (1), SW2.3 (1.), SW3.2 (1), SW3.3 (1.), U$1.1 (VSS), U$1.5 (R/W), U$1.6 (E), U$1.9 (DB2), U$1.10 (DB3), U$1.11 (DB4), U$1.12 (DB5), U$1.13 (DB6), U$1.14 (DB7), U$1.19 (BS1), U$1.20 (BS0); also elsewhere on the board
K1: C44.1, R45.2; also elsewhere on the board
K2: C45.1, R47.2; also elsewhere on the board
K3: C46.1, R49.2; also elsewhere on the board
MOSI: U$1.8 (SDIN); also elsewhere on the board
unnamed: R44.2, R45.1, SW1.1 (2), SW1.4 (.2)
unnamed: R46.2, R47.1, SW2.1 (2), SW2.4 (.2)
unnamed: R48.2, R49.1, SW3.1 (2), SW3.4 (.2)
unnamed: E1.A, R28.1, R29.1
unnamed: E1.B, R2.1, R26.1
unnamed: E2.B, R3.1, R32.1
unnamed: E2.A, R34.1, R35.1
unnamed: E3.B, R4.1, R38.1
unnamed: E3.A, R40.1, R41.1
O_DC: U$1.4 (D/C); also elsewhere on the board
O_RESET: U$1.16 (/RES); also elsewhere on the board
SCK: U$1.7 (SCLK); also elsewhere on the board

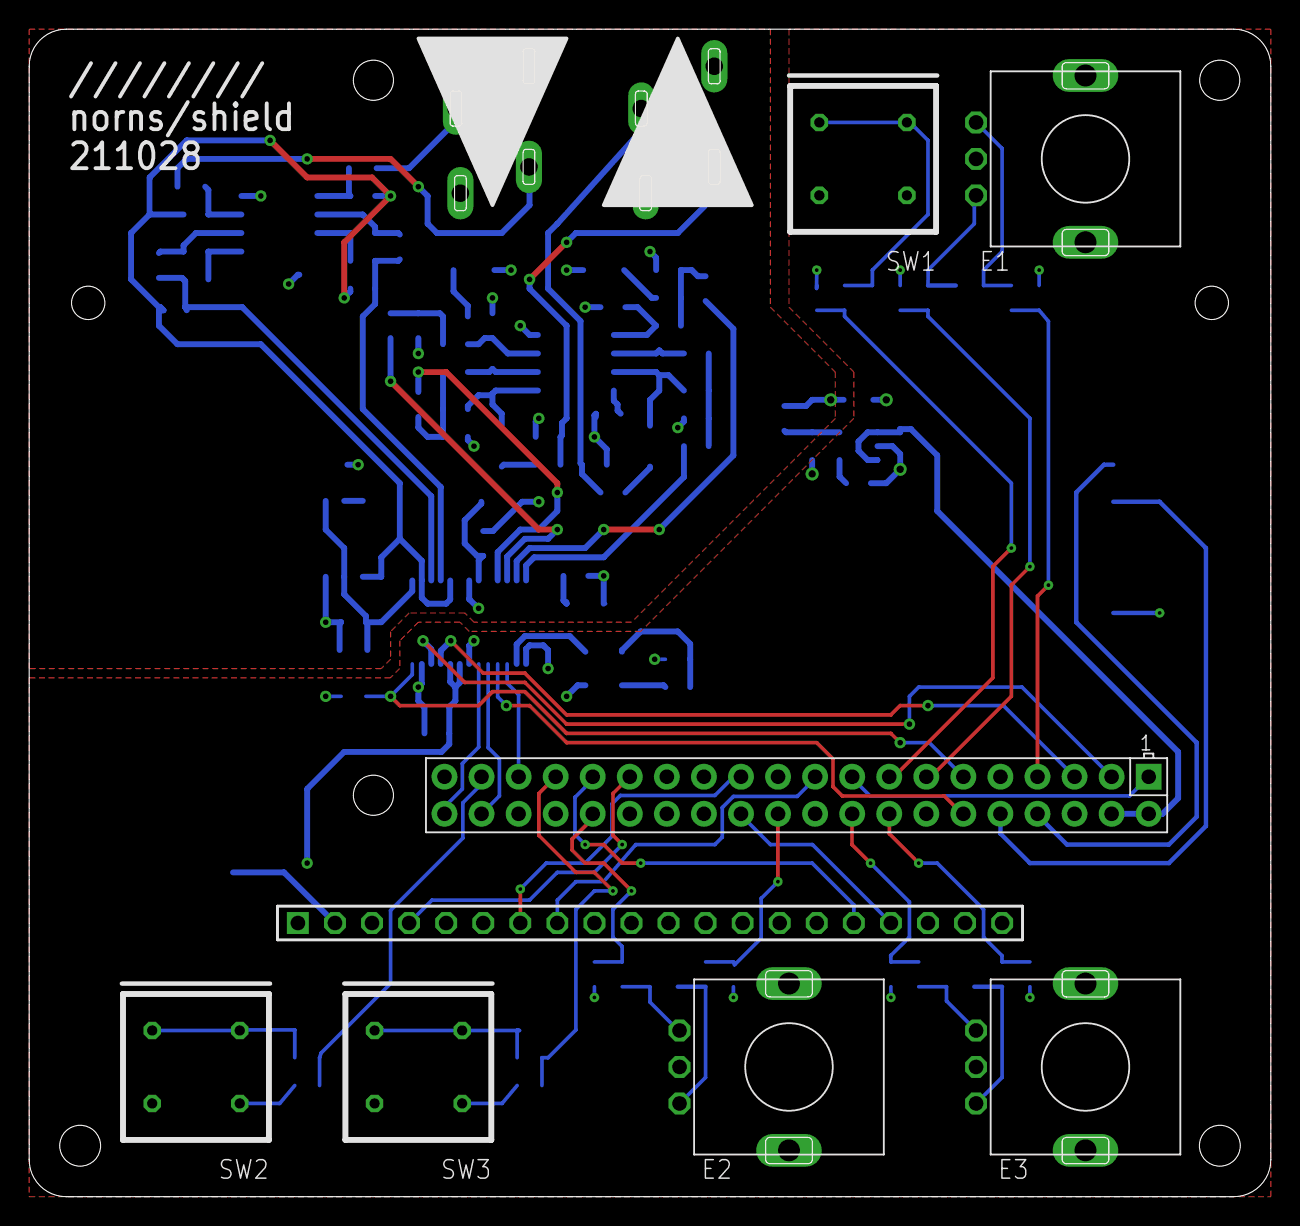
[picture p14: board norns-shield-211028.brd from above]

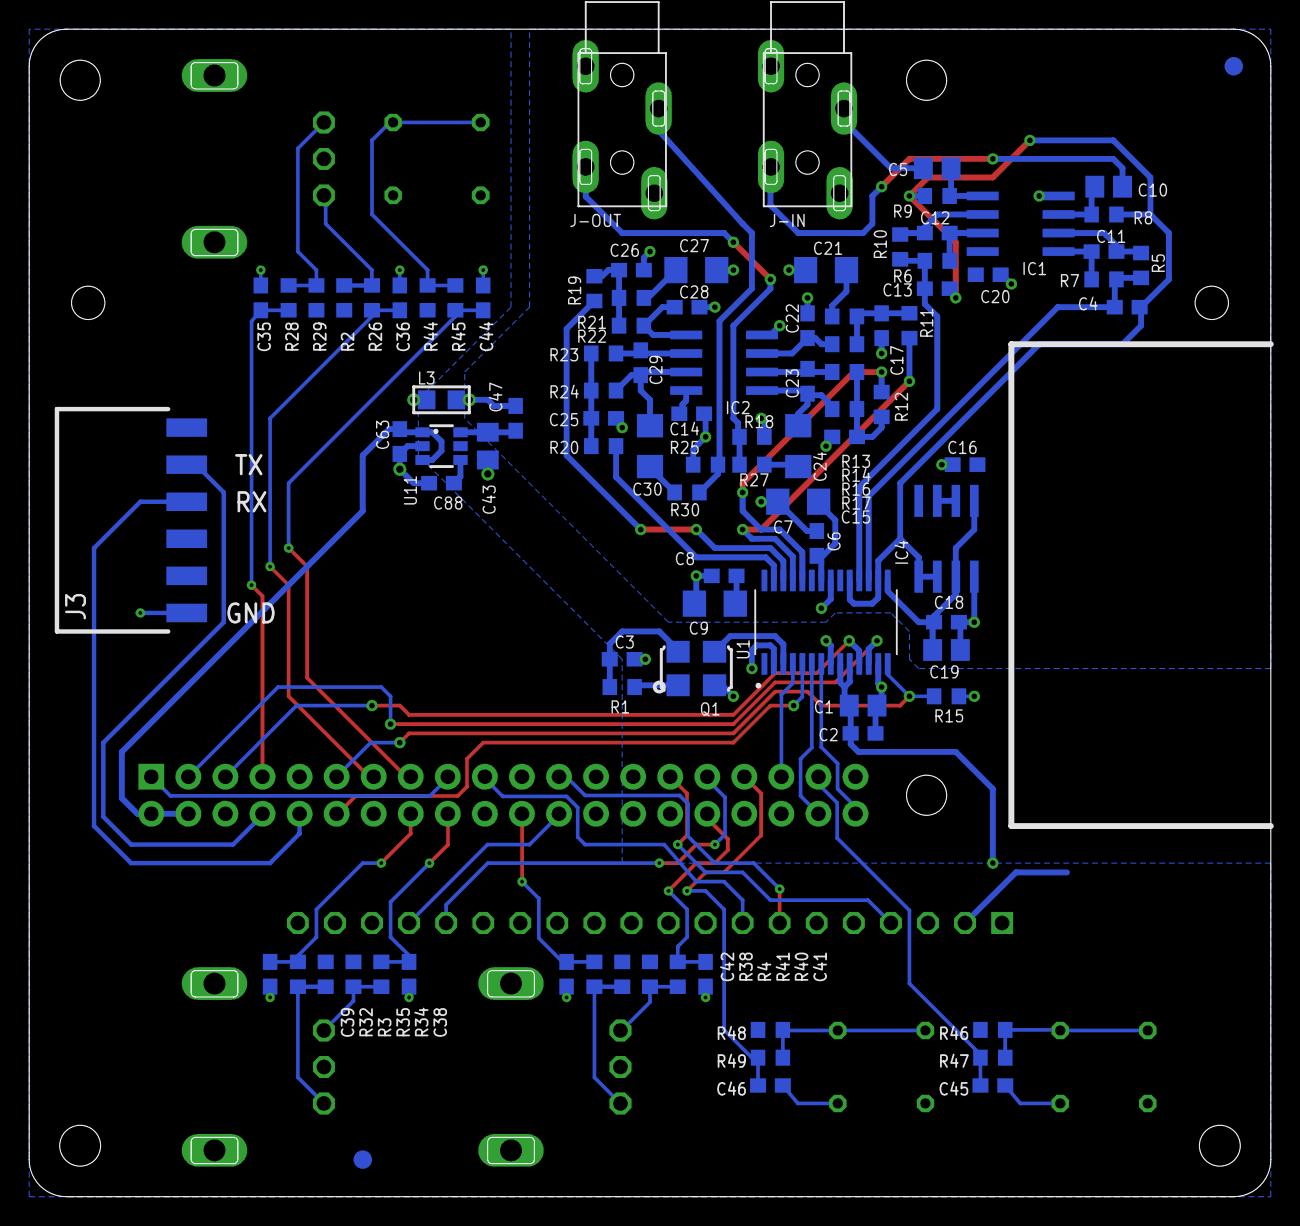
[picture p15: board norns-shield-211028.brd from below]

Board: 2 copper layers, 85.1 x 80.0 mm, 105 parts (97 on the bottom side), 74 nets.

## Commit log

2019-10-24 191021, add pullups to encoders
    [norns-shield.brd, norns-shield.sch]
2019-11-05 fix airwires
    [norns-shield.brd]
2019-11-06 fix airwire
    [norns-shield.brd]
2020-03-16 add dxf, plate build photos
    [norns-shield-plate-bottom.dxf, norns-shield-plate.dxf]
2020-03-16 insert img
2022-10-05 add all versions, draft
    [norns-shield-191106.brd, norns-shield-191106.ods, norns-shield-191106.sch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]

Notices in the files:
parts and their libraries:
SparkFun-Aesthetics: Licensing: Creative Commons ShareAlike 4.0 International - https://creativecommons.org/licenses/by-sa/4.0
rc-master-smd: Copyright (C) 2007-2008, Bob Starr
